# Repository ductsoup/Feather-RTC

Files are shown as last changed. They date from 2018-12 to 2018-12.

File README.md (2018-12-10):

# Feather RTC Time Clock
## Overview
We use time clocks and horns on the shop floor to signal shift changes and breaks. The problem with electro-mechanical clocks is they break after a while, are expensive, and also need to be manually reset every time there's a power failure or a time change. I've yet to see an electro-mechanical horn fail.

This design is a fraction of the cost and doesn't need to be manually reset. If WiFi is available it will sync to NTP. If not, the RTC will keep accurate time for years between power failures. It also adjusts automatically between standard and daylight saving time.

Please be careful if you're building or modifying this design because it uses AC line voltage which can be dangerous.

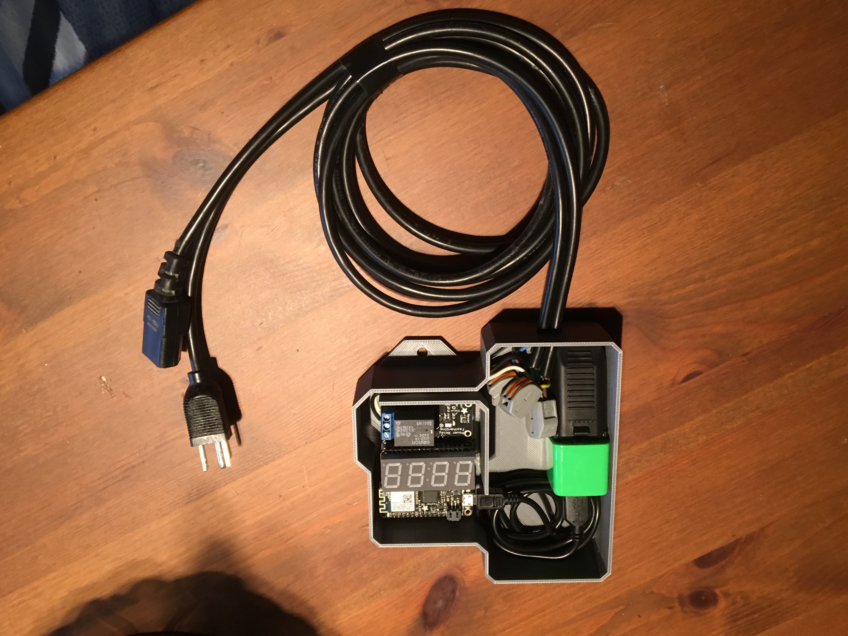
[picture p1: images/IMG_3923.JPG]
Final build


## Design
The only real challenge here is how to power the AVR, switch AC line voltages for the horn then fit all that into a compact enclosure that's durable enough for the shop floor. The smart phone charger cubes are a good way to accomplish that.

It turns out there are many good libraries for managing daylight savings on the AVR platform, in practice they're not entirely compatible. Here I've chosen to use WiFi101 and rewrite that little piece so it works reliably.

## Usage

Set your local timezone in rtc_management.h
```
#define TIME_ZONE -5  // America/New York
```

Set your WiFi connection in wifi_management.h
```
char *access_points[][2] = {
  {"myssid1", "mypassword1"},
  {"myssid2", "mypassword2"}
};
```
## Parts List
  * [Adafruit Feather M0 WiFi - ATSAMD21 + ATWINC1500](https://www.adafruit.com/product/3010)
  * [Adafruit 4-Digit 7-Segment LED Matrix Display FeatherWing](https://www.adafruit.com/product/3088)
  * [Adafruit DS3231 Precision RTC FeatherWing - RTC Add-on For Feather Boards](https://www.adafruit.com/product/3028)
  * [Adafruit Stacking Headers](https://www.adafruit.com/product/2830) (for the RTC only)
  * [Adafruit Power Relay FeatherWing](https://www.adafruit.com/product/3191)
  * [Adafruit FeatherWing Tripler Mini Kit - Prototyping Add-on For Feathers](https://www.adafruit.com/product/3417)
  * [USB cable - 6" A/MicroB](https://www.adafruit.com/product/898)
  * [Federal Signal 350-120-30 Vibratone Electro-Mechanical Horn, Surface Mount, 120 VAC](https://smile.amazon.com/gp/product/B003OU4HRA/ref=oh_aui_detailpage_o01_s00?ie=UTF8&psc=1)
  * AC power cables (salvaged from old PCs, printers)
  * USB charger cube (Lowes, drug stores, salvaged from your last smart phone)
  * [222-412 -  Standard Terminal Block, Grey, 222 Series, 2 Contacts, Terminal Block, Cable Mount, 12 AWG](https://www.newark.com/wago/222-412/terminal-block-pluggable-2-position/dp/45M7284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)
  * [	
222-413 -  Standard Terminal Block, Grey, 222 Series, 3 Contacts, Terminal Block, Cable Mount, 12 AWG ](https://www.newark.com/wago/222-413/terminal-block-pluggable-3-position/dp/28K2061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)
  * Hubbell RP102BKZ Commercial Straight connector or similar (Lowes)
    
## Enclosure and Assembly
This enclosure was printed in PLA. Use at least 50% infill, if you have the time 100% is better. 

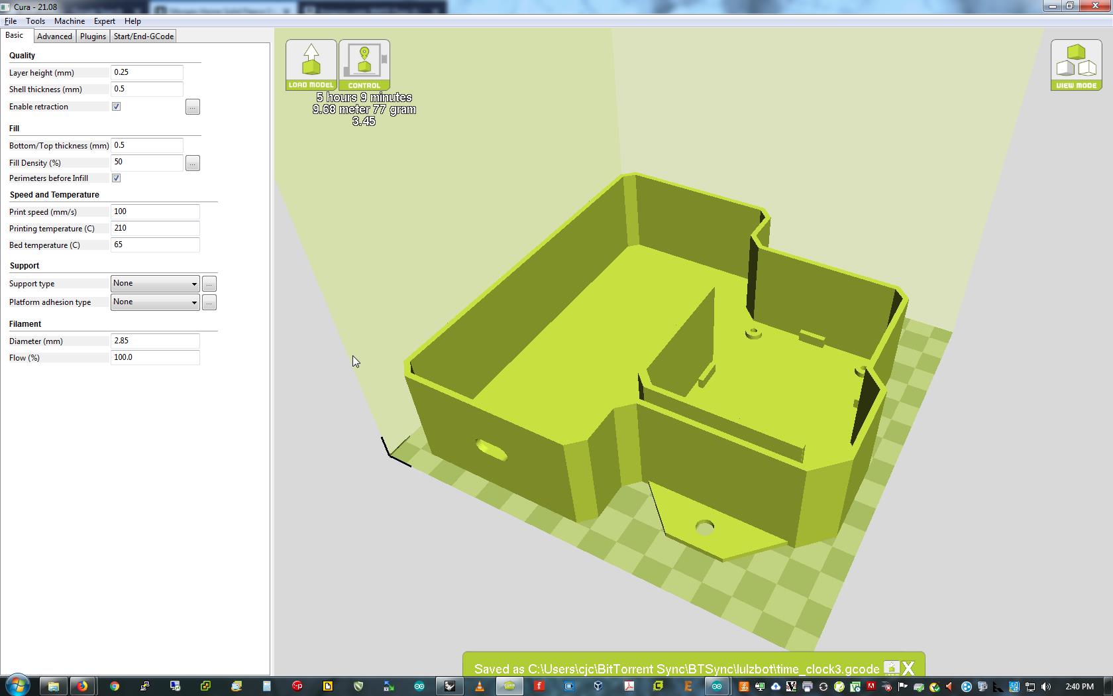
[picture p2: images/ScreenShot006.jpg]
Enclosure bottom

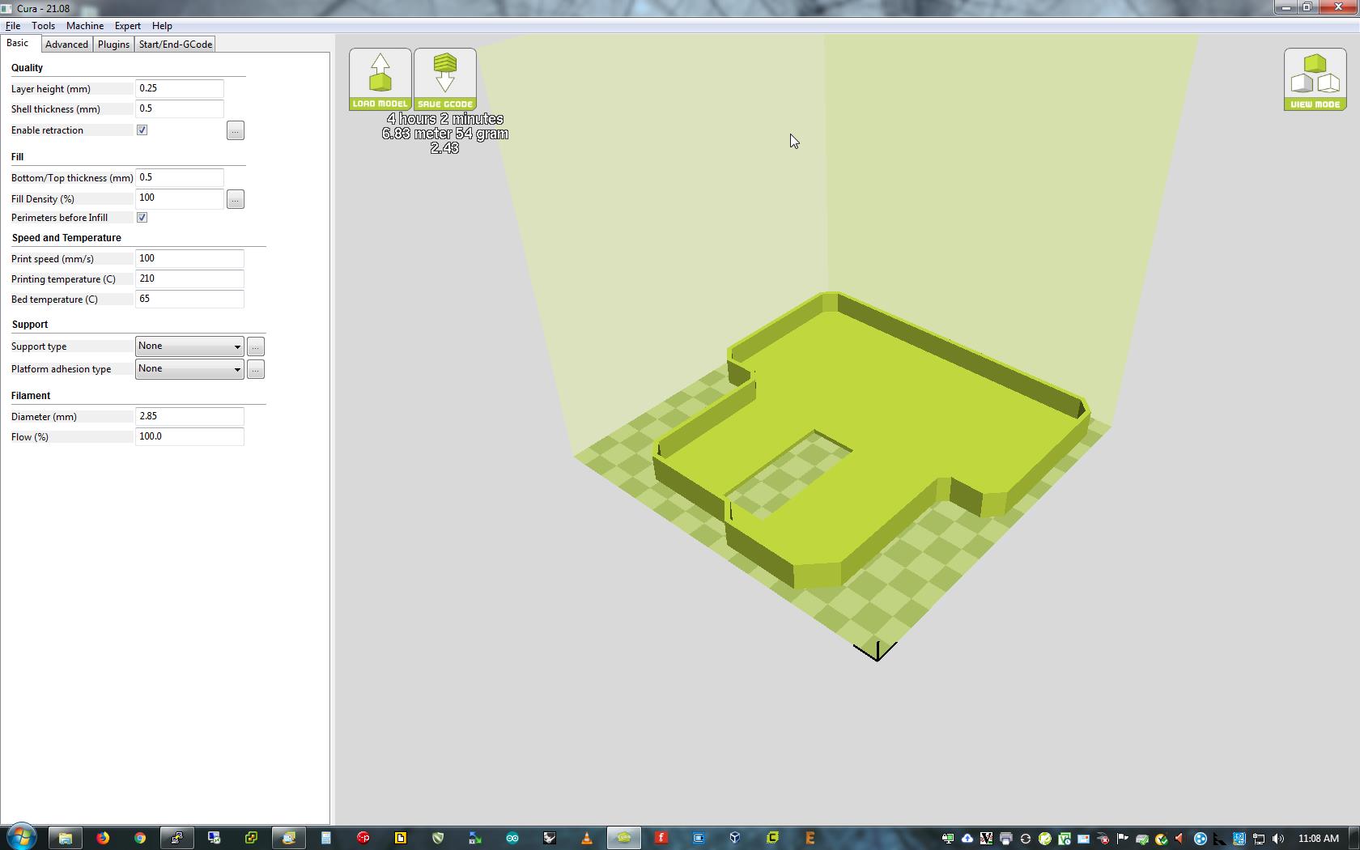
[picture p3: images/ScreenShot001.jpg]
Enclosure top


  * After printing hand tap then secure the Feather tripler board using 2.5mm nylon screws
  * Solder the Feather, RTC, LED and Relay wings (don't forget to solder the pad to jump pin 11 as the control for the relay)
  * Install the Feather, RTC and LED wings then use the checkout sketches to verify proper operation
  * Complete the AC wiring then mount the relay wing

The AC line voltage wiring should look something like this.
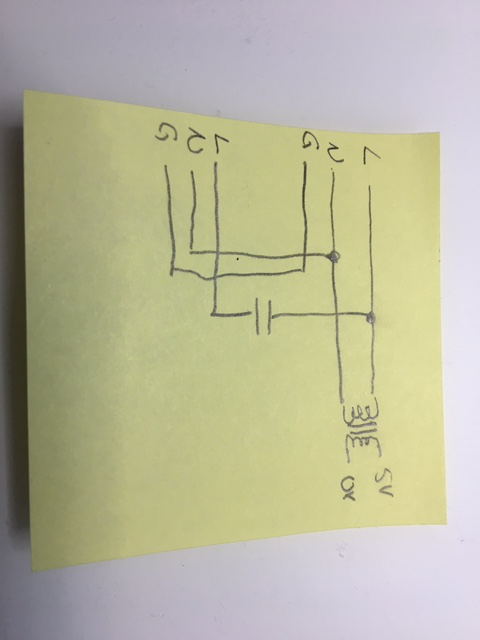
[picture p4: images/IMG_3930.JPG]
AC Schematic


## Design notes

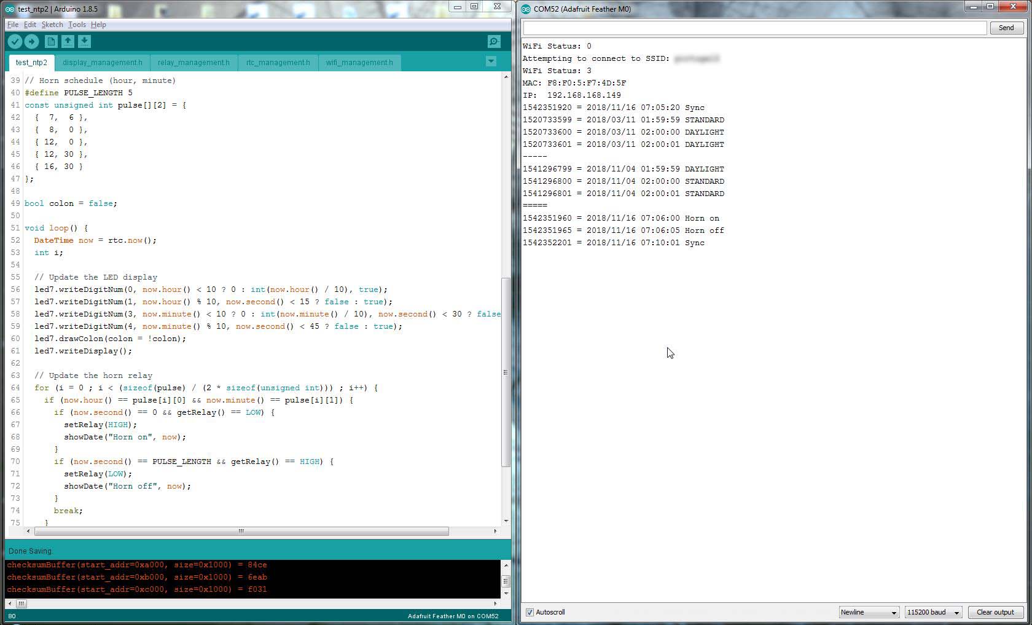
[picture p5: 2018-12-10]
images/ScreenShot004.jpg

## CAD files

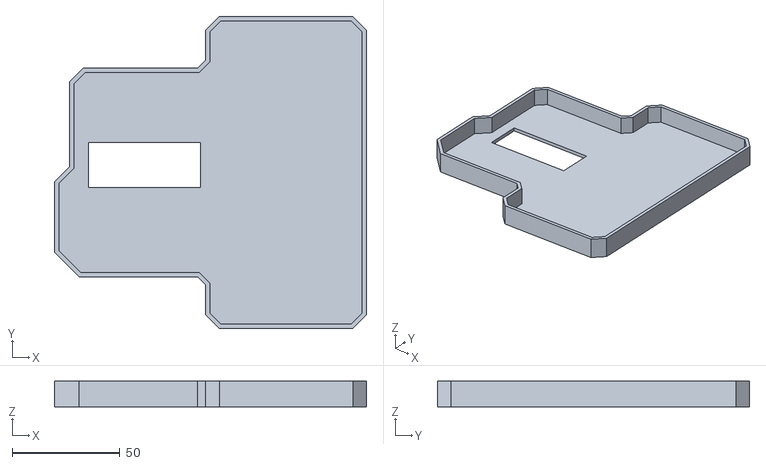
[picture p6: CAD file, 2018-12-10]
enclosure/enclosure_top.stl
144.5 x 144.5 x 12.0

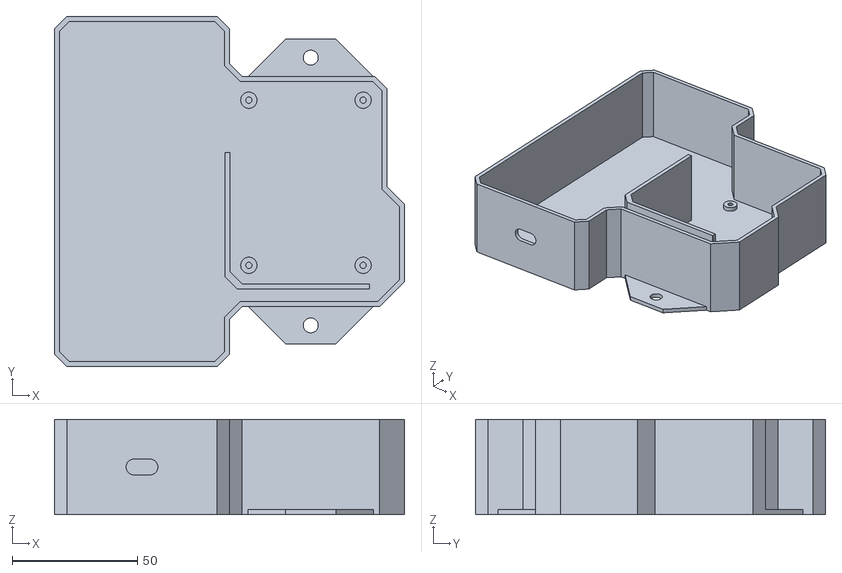
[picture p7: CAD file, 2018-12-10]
enclosure/enclosure_bottom.stl
140.0 x 140.0 x 38.0

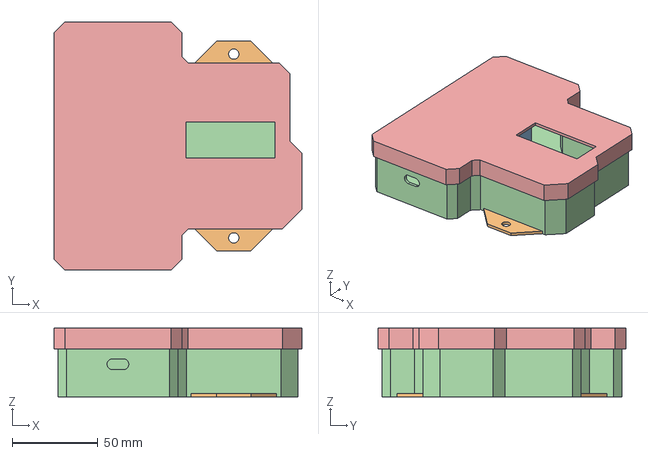
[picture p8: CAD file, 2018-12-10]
enclosure/enclosure_final.stp
144.5 x 144.5 x 40.0 mm

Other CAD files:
enclosure/enclosure_final.3dm

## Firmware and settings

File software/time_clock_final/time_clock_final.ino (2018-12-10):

/*
   Adafruit Feather M0 WiFi - ATSAMD21 + ATWINC1500
   https://www.adafruit.com/product/3010

   Adafruit 4-Digit 7-Segment LED Matrix Display FeatherWing
   https://www.adafruit.com/product/3088

   DS3231 Precision RTC FeatherWing - RTC Add-on For Feather Boards
   https://www.adafruit.com/product/3028
   https://www.adafruit.com/product/2830

    Adafruit Power Relay FeatherWing
    https://www.adafruit.com/product/3191
*/

#define DEBUG true

#include "relay_management.h"
#include "wifi_management.h"
#include "display_management.h"
#include "rtc_management.h"

void setup() {
  // Initialize the serial debug monitor
  Serial.begin(115200);
  delay(3000);

  // Initialize the 7-segment LED display
  begin_led7();

  // Initialize the relay
  begin_relay();
  
  // Initialize WiFi
  begin_wifi();

  // Initialize RTC
  begin_rtc();
  update_rtc();
#ifdef DEBUG
  test_dst();
#endif
}

// Horn schedule (24hour, minute)
#define PULSE_LENGTH 2
const unsigned int pulse[][2] = {
  {  8,  0 },   //  8:00 am
  { 12,  0 },   // 12:00 pm
  { 12, 30 },   // 12:30 pm
  { 16, 30 }    // 04:30 pm
};

bool colon = false;

void loop() {
  DateTime now = rtc.now();
  int i;

  // Update the LED display
  // The first decimal is the WiFi connection status, the rest are 15, 30 and 45 second intervals
  led7.writeDigitNum(0, now.hour() < 10 ? 0 : int(now.hour() / 10), WiFi.status() == WL_CONNECTED);
  led7.writeDigitNum(1, now.hour() % 10, now.second() < 15 ? false : true);
  led7.writeDigitNum(3, now.minute() < 10 ? 0 : int(now.minute() / 10), now.second() < 30 ? false : true);
  led7.writeDigitNum(4, now.minute() % 10, now.second() < 45 ? false : true);
  led7.drawColon(colon = !colon);
  led7.writeDisplay();

  // Update the horn relay
  for (i = 0 ; i < (sizeof(pulse) / (2 * sizeof(unsigned int))) ; i++) {
    if (now.hour() == pulse[i][0] && now.minute() == pulse[i][1]) {
      if (now.second() == 0 && getRelay() == LOW) {
        setRelay(HIGH);
        showDate("Horn on", now);
      }
      if (now.second() == PULSE_LENGTH && getRelay() == HIGH) {
        setRelay(LOW);
        showDate("Horn off", now);
      }
      break;
    }
  }

  // Adust the RTC daily at 02:00:00
  if (now.hour() == 2 && now.minute() == 0 && now.second() == 30) {
  //if (now.minute() % 5 == 0 && now.second() == 30) {
    update_rtc();
  }
  delay(1000);
}

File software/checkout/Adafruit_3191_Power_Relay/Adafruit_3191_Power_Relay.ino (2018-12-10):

/*
  Blink

  Turns an LED on for one second, then off for one second, repeatedly.

  Most Arduinos have an on-board LED you can control. On the UNO, MEGA and ZERO
  it is attached to digital pin 13, on MKR1000 on pin 6. LED_BUILTIN is set to
  the correct LED pin independent of which board is used.
  If you want to know what pin the on-board LED is connected to on your Arduino
  model, check the Technical Specs of your board at:
  https://www.arduino.cc/en/Main/Products

  modified 8 May 2014
  by Scott Fitzgerald
  modified 2 Sep 2016
  by Arturo Guadalupi
  modified 8 Sep 2016
  by Colby Newman

  This example code is in the public domain.

  http://www.arduino.cc/en/Tutorial/Blink
*/
#define RELAY_PIN 11
// the setup function runs once when you press reset or power the board
void setup() {
  // initialize digital pin LED_BUILTIN as an output.
  pinMode(LED_BUILTIN, OUTPUT);
  pinMode(RELAY_PIN, OUTPUT);
}

// the loop function runs over and over again forever
void loop() {
  digitalWrite(LED_BUILTIN, HIGH);   // turn the LED on (HIGH is the voltage level)
  digitalWrite(RELAY_PIN, HIGH);
  delay(5000);                       // wait for a second
  digitalWrite(LED_BUILTIN, LOW);    // turn the LED off by making the voltage LOW
  digitalWrite(RELAY_PIN, LOW);
  delay(5000);                       // wait for a second
}

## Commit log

2018-12-10 initial
    initial
    [enclosure_bottom.stl, enclosure_final.3dm, enclosure_final.stp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]
2018-12-10 Update README.md
    Added parts list, enclosure and assembly
2018-12-10 upload schematic
2018-12-10 Update README.md
    added AC schematic
